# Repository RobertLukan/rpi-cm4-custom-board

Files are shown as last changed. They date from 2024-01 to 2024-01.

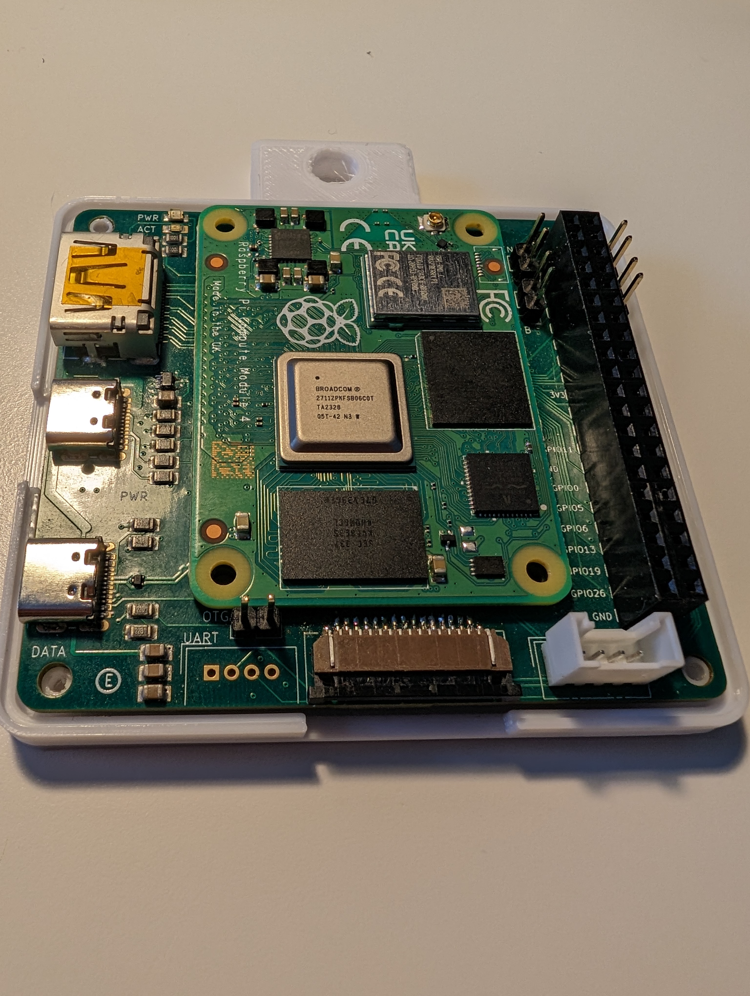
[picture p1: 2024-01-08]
pictures/PXL_20240108_122943070.jpg

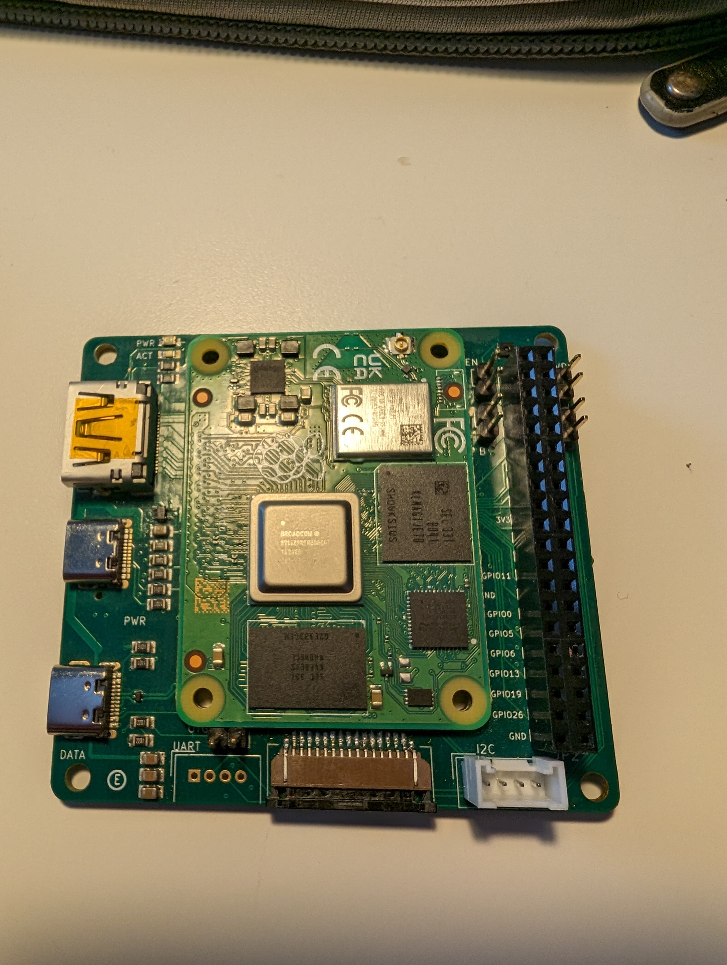
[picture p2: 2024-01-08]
pictures/PXL_20240108_123018562.jpg

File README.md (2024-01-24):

Based on my previous projects I needed a customized RPI4 carrier board with 2 cameras input. The initial idea was taken from this project: https://www.tindie.com/products/dronecz/minimal-carrier-board-for-compute-module-4/.

I made several changes such as 4-layer PCB, added second camera lanes, differential routing for both cameras and HDMI, added temperature sensor, and added I2C and UART connectors.

I have added also two jumpers that allow disabling wireless and Bluetooth. I have tested nearly every connection. SD card connector does not work if you are using RPI4CM with emmc, otherwise, it should(not the fault of this design but the RPI design decision that I was not aware of while making this board)

In general, I am quite happy with the setup. JLCPCB manufactured and assembled most of the parts. However, one board did not have Hirose connectors soldered properly, I have received a coupon. I have not touched the spacing for Hirose connectors, but I found it may be slightly off. It is hard to connect RPI for the first time. But I don't want to modify it as it has been working for several weeks.

USB connector can be used to connect external devices. To flash a CM the dedicated jumper(OTG) needs to be connected . It is just USB2.0 and it is not delivering any power. I have tested powered USB hub/docking station and it is working fine. In this way even Ethernet connection can be used (again being limited to USB2.0)

I also created 3D-printed housing. It is my first 3d design of this type/scale, but it works. It does not have cutouts for HDMI and USB2.0 as I dont need them.

In order to use both cameras, config.txt file has to include both overlays as defined below, for my two cameras:

dtparam=i2c_arm=on

dtoverlay=imx708,cam0

dtoverlay=imx477,cam1

The majority of the connectors were assembled by JLCPCB(without I2C and camera connectors - not available at that time), I have included the production directory where all the details are attached. The positions of parts are not 100% aligned, so make sure if you are asking JLCPCB to assemble parts to align them correctly. It is very important to order the correct camera connector: https://www.digikey.at/en/products/detail/amphenol-cs-fci/SFW15R-1STAE1LF/4270877

I made several design decisions that suited my needs, such as different GPIO header connector, and 4-pin Groove connectors for UART and I2C, so they might not be suitable for your needs.

One important detail, I am powering this board with the Raspberry Pi power supply. Other power supplies with USB C connector might not work as RPI requires quite some power and I would need to implement USB PD.

Update:
I needed power(5V) for an external USB device. I knew that I could connect a powered USB docking station(hub), however, that requires yet another power supply. As I just needed to power the USB microphone, that was an overkill. I looked at my diagram and I noticed that I can take 5V from GPIO and connect one of the pins at the OTG jumper(as shown below). An important detail is that the track is not designed to carry a lot of current, so be reasonable. 



License:
Please feel free to use the design. Released under the following license: 
https://ohwr.org/cern_ohl_p_v2.txt

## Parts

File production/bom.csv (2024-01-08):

Designator | Footprint | Quantity | Value | LCSC Part #
@HOLE0, @HOLE1, @HOLE2, @HOLE3, @HOLE4, @HOLE5, @HOLE6, @HOLE7 |  | 8
ACT0 | CHIPLED_0805_NOOUTLINE | 1 | GREEN
C0, CAMERA0 | SFW15R2STE1LF | 2 | SFW15R-2STE1LF
C1, C2, C3, C4 | C0805 | 4 | 10uF
C5 | C0805 | 1 | 100nF
HDMI0 | HDMI_MOLEX_47151-0001 | 1 | HDMI_MOLEX_47151-0001 | C428484
IC0 | SOT65P210X110-5N | 1 | MC74VHC1G14DFT1G
J1, J2 | DF40C100DS04V51 | 2 | DF40C-100DS-0.4V_51_ | DF40C-100DS-0.4V(51)
JP1, JP3, JP4, JP5, JP6 | PinHeader_1x02_P2.54mm_Vertical | 5 | Jumper_2_Open
JP2 | 2X20 | 1 | PINHD-2X20
PWR0 | CHIPLED_0805_NOOUTLINE | 1 | RED/ORANGE
R1, R2 | R0805 | 2 | 1k
R10, R11 | R0805 | 2 | 2.2k
R3, R4, R5 | R0805 | 3 | 10K
R6, R7, R8, R9 | R0805 | 4 | 5.1k
SD_CARD0 | TFP09-2--12B | 1 | MICRO_SD_CARD_
U1, U2 | NS-Tech_Grove_1x04_P2mm_Vertical | 2 | ~
U3 | Texas_DRT-3 | 1 | TPD2EUSB30A
U4 | Sensirion_DFN-4-1EP_2x2mm_P1mm_EP0.7x1.6mm | 1 | SHTC3
US0, US1 | HRO_31_M_12_USB_C | 2 | HRO_31_M_12_USB_C

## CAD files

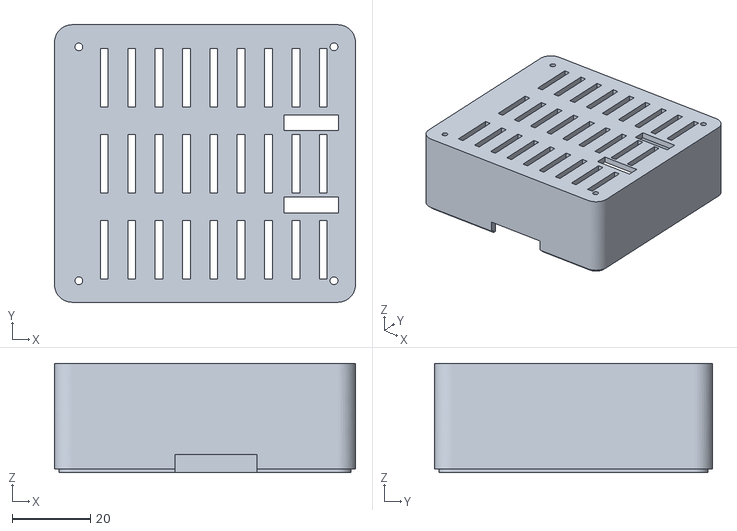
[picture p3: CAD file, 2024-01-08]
Case/RPI Box v1 Top.stl
77.0 x 71.0 x 28.0

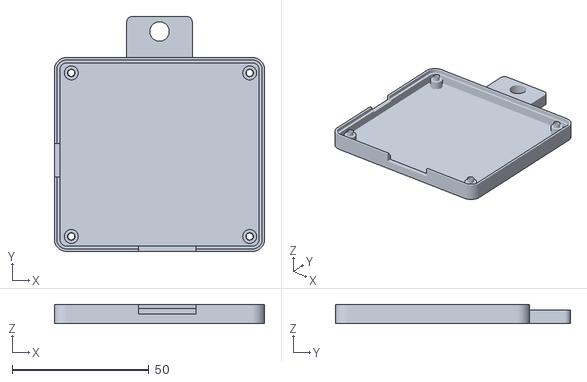
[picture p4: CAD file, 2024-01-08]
Case/RPI Box v1 Bottom.stl
77.0 x 86.0 x 7.00

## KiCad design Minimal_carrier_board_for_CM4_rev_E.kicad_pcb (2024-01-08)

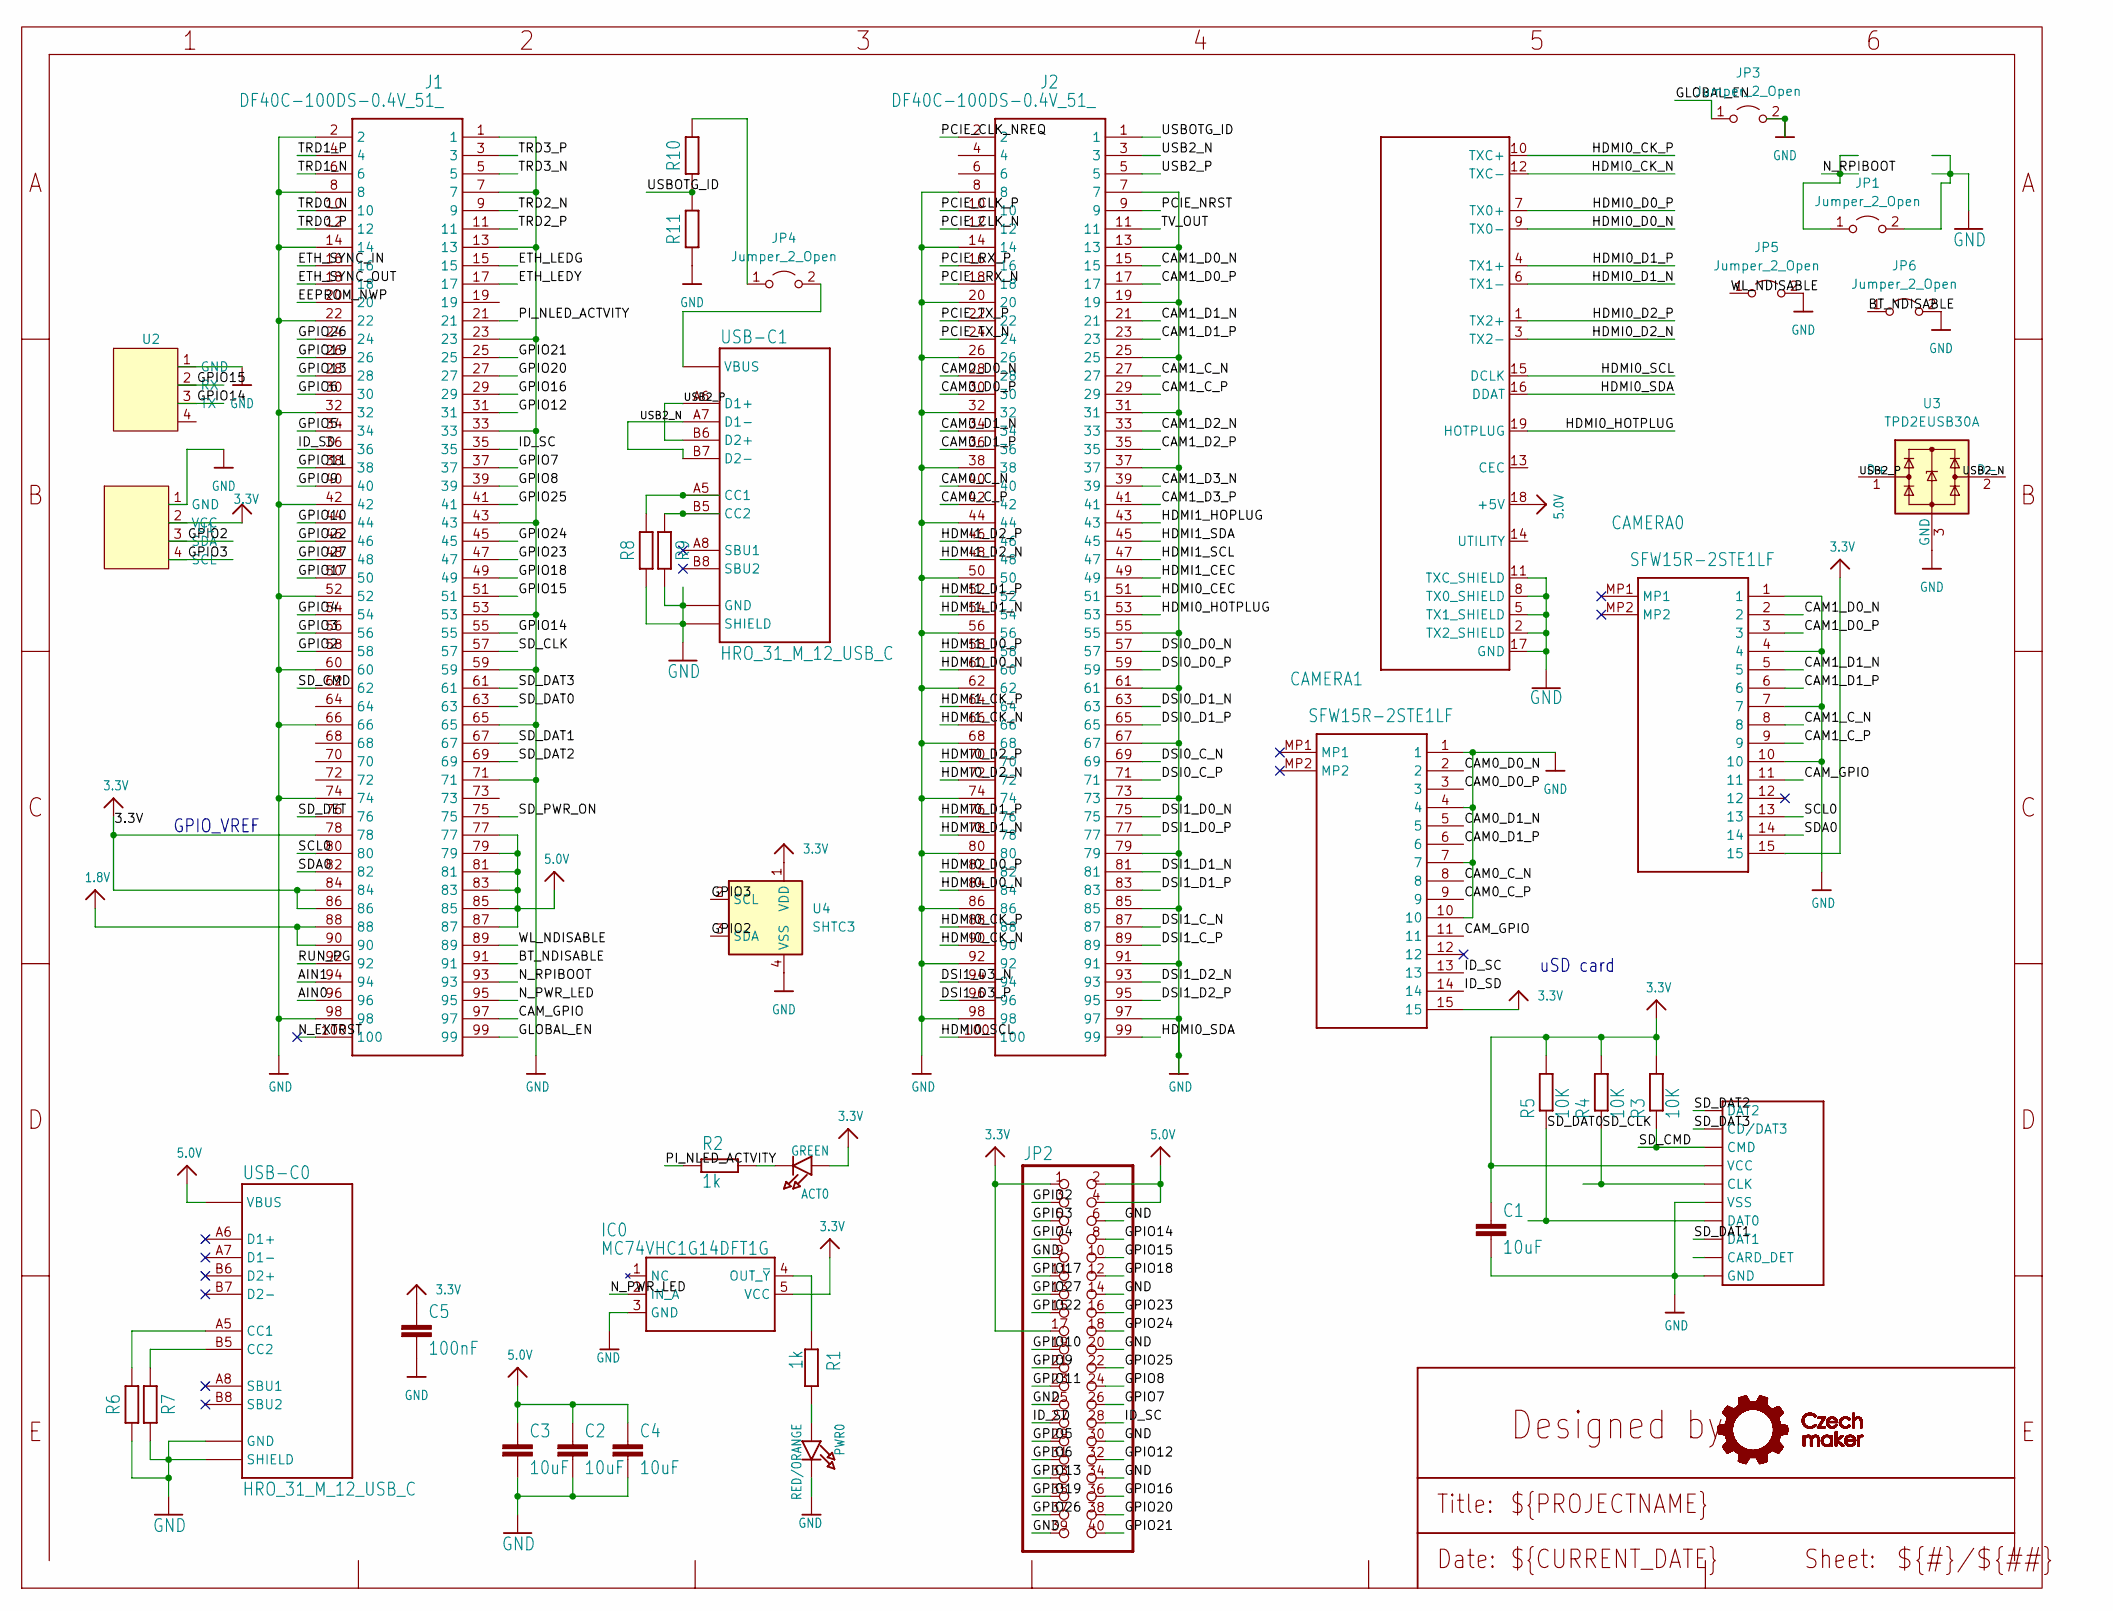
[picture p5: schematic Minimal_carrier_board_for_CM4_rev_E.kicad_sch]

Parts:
ACT0: GREEN; CHIPLED_0805_NOOUTLINE
C1, C2, C3, C4: 10uF; C0805
C5: 100nF; C0805
CAMERA0, CAMERA1: SFW15R-2STE1LF; SFW15R2STE1LF
HDMI0: HDMI_MOLEX_47151-0001; LCSC C428484
IC0: MC74VHC1G14DFT1G; SOT65P210X110-5N
J1: DF40C-100DS-0.4V_51_; DF40C100DS04V51; LCSC DF40C-100DS-0.4V(51)
J2: DF40C-100DS-0.4V_51_; DF40C100DS04V51
JP1, JP3, JP4, JP5, JP6: Jumper_2_Open; PinHeader_1x02_P2.54mm_Vertical
JP2: PINHD-2X20; 2X20
PWR0: RED/ORANGE; CHIPLED_0805_NOOUTLINE
R1, R2: 1k; R0805
R3, R4, R5: 10K; R0805
R6, R7, R8, R9: 5.1k; R0805
R10, R11: 2.2k; R0805
SD_CARD0: MICRO_SD_CARD_; TFP09-2--12B
U1, U2: NS-Tech_Grove_1x04_P2mm_Vertical
U3: TPD2EUSB30A; Texas_DRT-3
U4: SHTC3; Sensirion_DFN-4-1EP_2x2mm_P1mm_EP0.7x1.6mm
USB-C0, USB-C1: HRO_31_M_12_USB_C

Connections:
1.8V: J1.88, J1.90
3.3V: ACT0.A, C1.1, C5.1, CAMERA0.15, CAMERA1.15, IC0.5 (VCC), J1.78, J1.84, J1.86, JP2.1, JP2.17, R3.2, R4.2, R5.2, SD_CARD0.VCC, U1.2 (VCC), U4.1 (VDD); also elsewhere on the board
5.0V: C2.1, C3.1, C4.1, HDMI0.18 (+5V), J1.77, J1.79, J1.81, J1.83, J1.85, J1.87, JP2.2, JP2.4, USB-C0.A4 (VBUS), USB-C0.A9 (VBUS), USB-C0.B4 (VBUS), USB-C0.B9 (VBUS); also elsewhere on the board
/AIN0: J1.96
/AIN1: J1.94
/BT_NDISABLE: J1.91, JP6.1 (A)
/CAM0_C_N: CAMERA1.8, J2.40; also elsewhere on the board
/CAM0_C_P: CAMERA1.9, J2.42; also elsewhere on the board
/CAM0_D0_N: CAMERA1.2, J2.28; also elsewhere on the board
/CAM0_D0_P: CAMERA1.3, J2.30; also elsewhere on the board
/CAM0_D1_N: CAMERA1.5, J2.34; also elsewhere on the board
/CAM0_D1_P: CAMERA1.6, J2.36; also elsewhere on the board
/CAM1_C_N: CAMERA0.8, J2.27
/CAM1_C_P: CAMERA0.9, J2.29
/CAM1_D0_N: CAMERA0.2, J2.15
/CAM1_D0_P: CAMERA0.3, J2.17
/CAM1_D1_N: CAMERA0.5, J2.21
/CAM1_D1_P: CAMERA0.6, J2.23
/CAM1_D2_N: J2.33
/CAM1_D2_P: J2.35
/CAM1_D3_N: J2.39
/CAM1_D3_P: J2.41
/CAM_GPIO: CAMERA0.11, CAMERA1.11, J1.97; also elsewhere on the board
/DSI0_C_N: J2.69
/DSI0_C_P: J2.71
/DSI0_D0_N: J2.57
/DSI0_D0_P: J2.59
/DSI0_D1_N: J2.63
/DSI0_D1_P: J2.65
/DSI1_C_N: J2.87
/DSI1_C_P: J2.89
/DSI1_D0_N: J2.75
/DSI1_D0_P: J2.77
/DSI1_D1_N: J2.81
/DSI1_D1_P: J2.83
/DSI1_D2_N: J2.93
/DSI1_D2_P: J2.95
/DSI1_D3_N: J2.94
/DSI1_D3_P: J2.96
/EEPROM_NWP: J1.20
/ETH_LEDG: J1.15
/ETH_LEDY: J1.17
/ETH_SYNC_IN: J1.16
/ETH_SYNC_OUT: J1.18
/GLOBAL_EN: J1.99, JP3.1 (A)
/GPIO2: J1.58, JP2.3, U1.3 (SDA), U4.3 (SDA)
/GPIO3: J1.56, JP2.5, U1.4 (SCL), U4.2 (SCL)
/GPIO4: J1.54, JP2.7
/GPIO5: J1.34, JP2.29
/GPIO6: J1.30, JP2.31
/GPIO7: J1.37, JP2.26
/GPIO8: J1.39, JP2.24
/GPIO9: J1.40, JP2.21
/GPIO10: J1.44, JP2.19
/GPIO11: J1.38, JP2.23
/GPIO12: J1.31, JP2.32
/GPIO13: J1.28, JP2.33
/GPIO14: J1.55, JP2.8, U2.3 (TX)
/GPIO15: J1.51, JP2.10, U2.2 (RX)
/GPIO16: J1.29, JP2.36
/GPIO17: J1.50, JP2.11
/GPIO18: J1.49, JP2.12
/GPIO19: J1.26, JP2.35
/GPIO20: J1.27, JP2.38
/GPIO21: J1.25, JP2.40
/GPIO22: J1.46, JP2.15
/GPIO23: J1.47, JP2.16
/GPIO24: J1.45, JP2.18
/GPIO25: J1.41, JP2.22
/GPIO26: J1.24, JP2.37
/GPIO27: J1.48, JP2.13
/HDMI0_CEC: J2.51
/HDMI0_CK_N: HDMI0.12 (TXC-), J2.90
/HDMI0_CK_P: HDMI0.10 (TXC+), J2.88
/HDMI0_D0_N: HDMI0.9 (TX0-), J2.84
/HDMI0_D0_P: HDMI0.7 (TX0+), J2.82
/HDMI0_D1_N: HDMI0.6 (TX1-), J2.78
/HDMI0_D1_P: HDMI0.4 (TX1+), J2.76
/HDMI0_D2_N: HDMI0.3 (TX2-), J2.72
/HDMI0_D2_P: HDMI0.1 (TX2+), J2.70
/HDMI0_HOTPLUG: HDMI0.19 (HOTPLUG), J2.53
/HDMI0_SCL: HDMI0.15 (DCLK), J2.100
/HDMI0_SDA: HDMI0.16 (DDAT), J2.99
/HDMI1_CEC: J2.49
/HDMI1_CK_N: J2.66
/HDMI1_CK_P: J2.64
/HDMI1_D0_N: J2.60
/HDMI1_D0_P: J2.58
/HDMI1_D1_N: J2.54
/HDMI1_D1_P: J2.52
/HDMI1_D2_N: J2.48
/HDMI1_D2_P: J2.46
/HDMI1_HOPLUG: J2.43
/HDMI1_SCL: J2.47
/HDMI1_SDA: J2.45
/ID_SC: CAMERA1.13, J1.35, JP2.28; also elsewhere on the board
/ID_SD: CAMERA1.14, J1.36, JP2.27; also elsewhere on the board
/N_EXTRST: J1.100
/N_PWR_LED: IC0.2 (IN_A), J1.95
/N_RPIBOOT: J1.93, JP1.1 (A)
/PCIE_CLK_N: J2.12
/PCIE_CLK_NREQ: J2.2
/PCIE_CLK_P: J2.10
/PCIE_NRST: J2.9
/PCIE_RX_P: J2.16
/PCIE_TX_N: J2.24
/PCIE_TX_P: J2.22
/PCIE__RX_N: J2.18
/PI_NLED_ACTVITY: J1.21, R2.1
/RUN_PG: J1.92
/SCL0: CAMERA0.13, J1.80
/SDA0: CAMERA0.14, J1.82
/SD_CLK: J1.57, R4.1, SD_CARD0.CLK
/SD_CMD: J1.62, R3.1, SD_CARD0.CMD
/SD_DAT0: J1.63, R5.1, SD_CARD0.DAT0
/SD_DAT1: J1.67, SD_CARD0.DAT1
/SD_DAT2: J1.69, SD_CARD0.DAT2
/SD_DAT3: J1.61, SD_CARD0.CD/DAT3
/SD_DET: J1.76
/SD_PWR_ON: J1.75
/TRD0_N: J1.10
/TRD0_P: J1.12
/TRD1_N: J1.6
/TRD1_P: J1.4
/TRD2_N: J1.9
/TRD2_P: J1.11
/TRD3_N: J1.5
/TRD3_P: J1.3
/TV_OUT: J2.11
/USB2_N: J2.3, U3.2 (D-), USB-C1.A7 (D1-), USB-C1.B7 (D2-); also elsewhere on the board
/USB2_P: J2.5, U3.1 (D+), USB-C1.A6 (D1+), USB-C1.B6 (D2+); also elsewhere on the board
/USBOTG_ID: J2.1, R10.1, R11.2
/WL_NDISABLE: J1.89, JP5.1 (A)
GND: C1.2, C2.2, C3.2, C4.2, C5.2, CAMERA0.1, CAMERA0.4, CAMERA0.7, CAMERA0.10, CAMERA1.1, CAMERA1.4, CAMERA1.7, CAMERA1.10, HDMI0.2 (TX2_SHIELD), HDMI0.5 (TX1_SHIELD), HDMI0.8 (TX0_SHIELD), HDMI0.11 (TXC_SHIELD), HDMI0.17 (GND), IC0.3 (GND), J1.1, J1.2, J1.7, J1.8, J1.13, J1.14, J1.22, J1.23, J1.32, J1.33, J1.42, J1.43, J1.52, J1.53, J1.59, J1.60, J1.65, J1.66, J1.71, J1.74, J1.98, J2.7, J2.8, J2.13, J2.14, J2.19, J2.20, J2.25, J2.26, J2.31, J2.32, J2.37, J2.38, J2.44, J2.50, J2.55, J2.56, J2.61, J2.62, J2.67, J2.68, J2.73, J2.74, J2.79, J2.80, J2.85, J2.86, J2.91, J2.92, J2.97, J2.98, JP1.2 (B), JP2.6, JP2.9, JP2.14, JP2.20, JP2.25, JP2.30, JP2.34, JP2.39, JP3.2 (B), JP5.2 (B), JP6.2 (B), PWR0.C, R6.1, R7.2, R8.1, R9.2, R11.1, SD_CARD0.GND, SD_CARD0.GND@1 (GND), SD_CARD0.GND@2 (GND), SD_CARD0.GND@3 (VSS), SD_CARD0.VSS (GND), U1.1 (GND), U2.1 (GND), U3.3 (GND), U4.4 (VSS), USB-C0.A1 (GND), USB-C0.A12 (GND), USB-C0.B1 (GND), USB-C0.B12 (GND), USB-C0.S1 (SHIELD), USB-C0.S2 (SHIELD), USB-C0.S3 (SHIELD), USB-C0.S4 (SHIELD), USB-C1.A1 (GND), USB-C1.A12 (GND), USB-C1.B1 (GND), USB-C1.B12 (GND), USB-C1.S1 (SHIELD), USB-C1.S2 (SHIELD), USB-C1.S3 (SHIELD), USB-C1.S4 (SHIELD); also elsewhere on the board
unnamed: ACT0.C, R2.2
unnamed: IC0.4 (OUT_~Y), R1.1
unnamed: JP4.1 (A), R10.2
unnamed 137: JP4.2 (B), USB-C1.A4 (VBUS), USB-C1.A9 (VBUS), USB-C1.B4 (VBUS), USB-C1.B9 (VBUS); also elsewhere on the board
unnamed: PWR0.A, R1.2
unnamed 139: R6.2, USB-C0.A5 (CC1); also elsewhere on the board
unnamed 140: R7.1, USB-C0.B5 (CC2); also elsewhere on the board
unnamed 141: R8.2, USB-C1.A5 (CC1); also elsewhere on the board
unnamed 142: R9.1, USB-C1.B5 (CC2); also elsewhere on the board

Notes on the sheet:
uSD card
GPIO_VREF

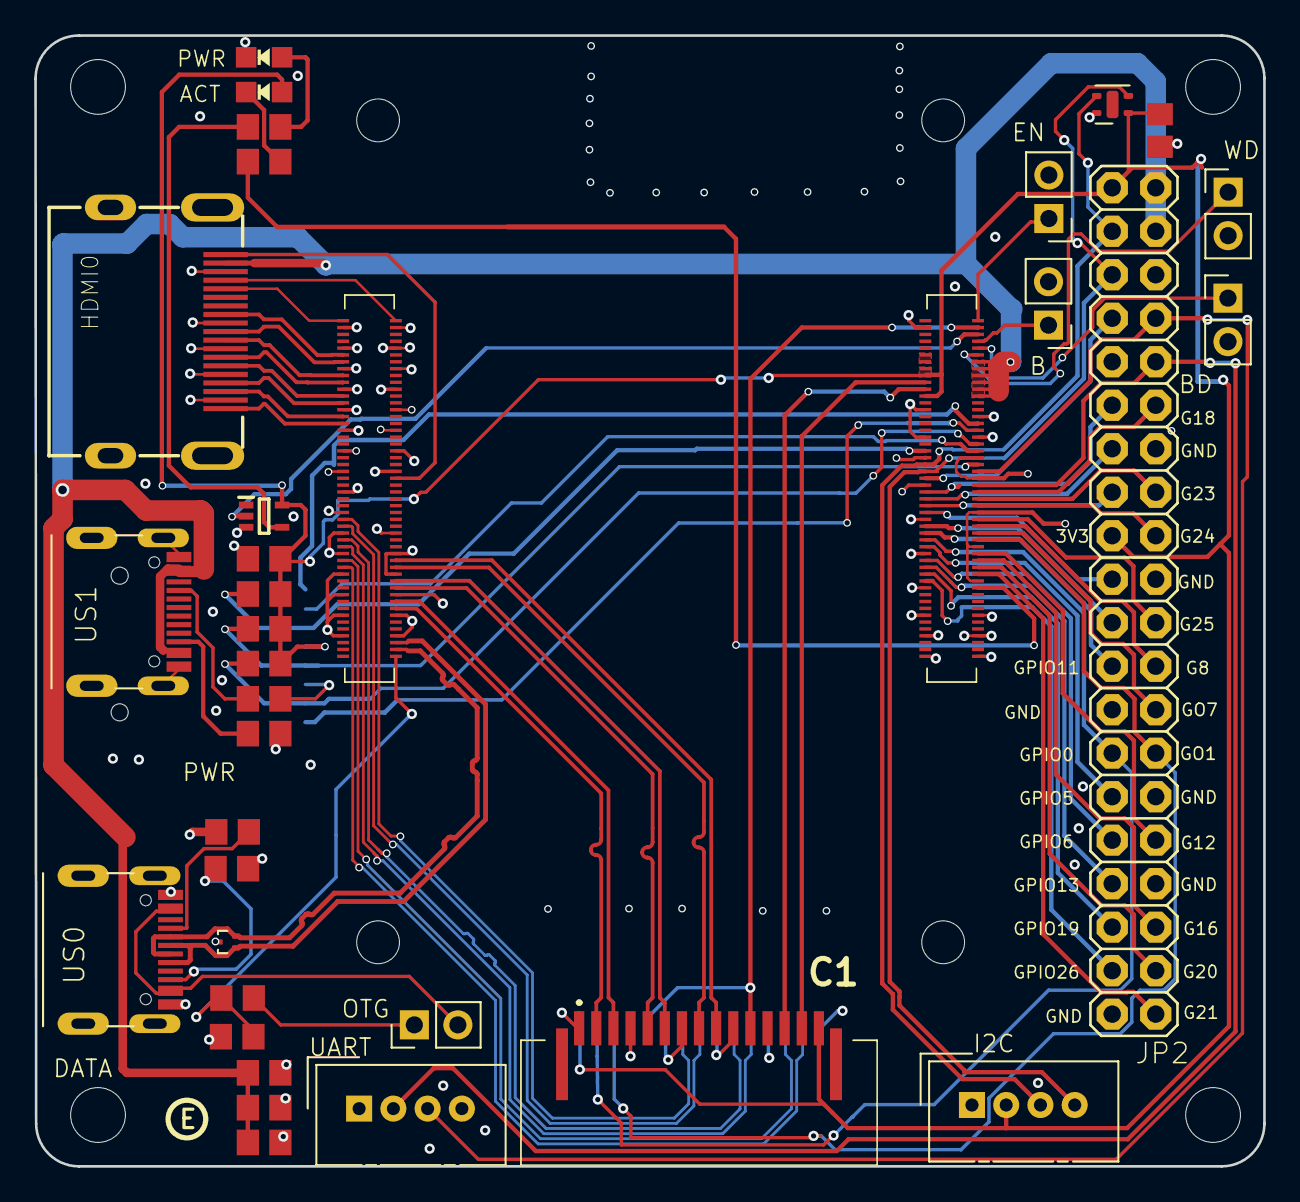
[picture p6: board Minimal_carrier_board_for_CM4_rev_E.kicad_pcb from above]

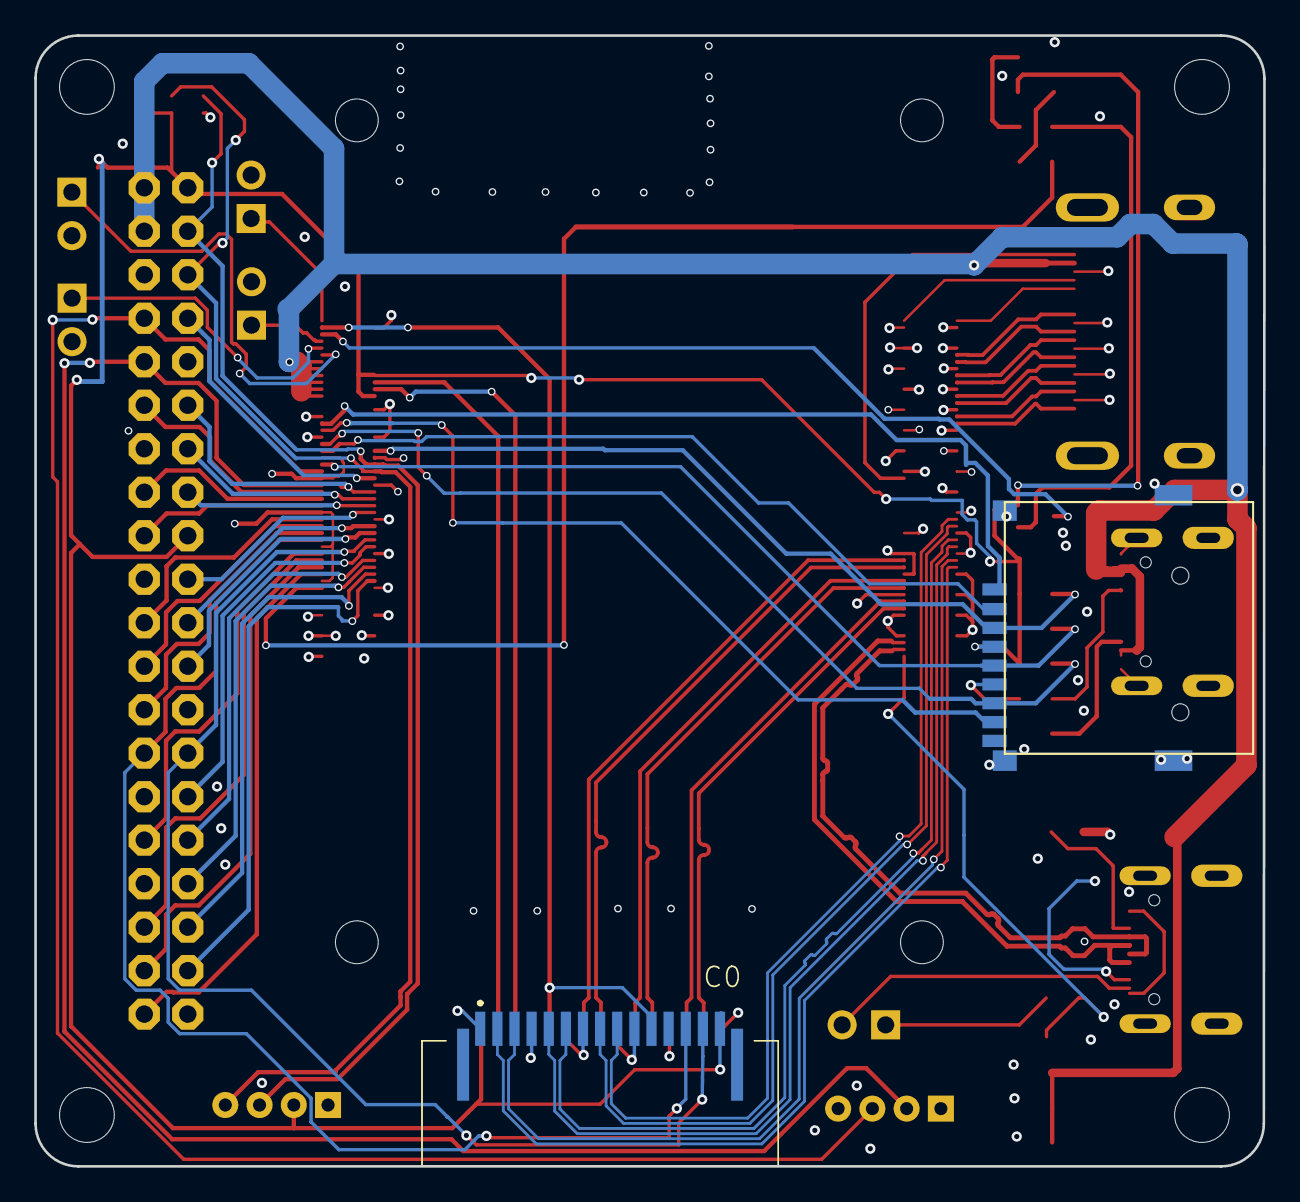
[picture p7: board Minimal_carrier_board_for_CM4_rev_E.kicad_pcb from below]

Board: 4 copper layers, 71.8 x 66.0 mm, 45 parts (2 on the bottom side), 82 nets.

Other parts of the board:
@HOLE0, @HOLE1, @HOLE2, @HOLE3, @HOLE4, @HOLE5, @HOLE6, @HOLE7: (no value)
C0: SFW15R-2STE1LF; SFW15R2STE1LF
US0, US1: HRO_31_M_12_USB_C

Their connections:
3.3V: C0.15; also elsewhere on the board
5.0V: US1.A4 (VBUS), US1.A9 (VBUS), US1.B4 (VBUS), US1.B9 (VBUS); also elsewhere on the board
/CAM0_C_N: C0.8; also elsewhere on the board
/CAM0_C_P: C0.9; also elsewhere on the board
/CAM0_D0_N: C0.2; also elsewhere on the board
/CAM0_D0_P: C0.3; also elsewhere on the board
/CAM0_D1_N: C0.5; also elsewhere on the board
/CAM0_D1_P: C0.6; also elsewhere on the board
/CAM_GPIO: C0.11; also elsewhere on the board
/ID_SC: C0.13; also elsewhere on the board
/ID_SD: C0.14; also elsewhere on the board
/USB2_N: US0.A7 (D1-), US0.B7 (D2-); also elsewhere on the board
/USB2_P: US0.A6 (D1+), US0.B6 (D2+); also elsewhere on the board
GND: C0.1, C0.4, C0.7, C0.10, US0.A1 (GND), US0.A12 (GND), US0.B1 (GND), US0.B12 (GND), US0.S1 (SHIELD), US0.S2 (SHIELD), US0.S3 (SHIELD), US0.S4 (SHIELD), US1.A1 (GND), US1.A12 (GND), US1.B1 (GND), US1.B12 (GND), US1.S1 (SHIELD), US1.S2 (SHIELD), US1.S3 (SHIELD), US1.S4 (SHIELD); also elsewhere on the board
unnamed 137: US0.A4 (VBUS), US0.A9 (VBUS), US0.B4 (VBUS), US0.B9 (VBUS); also elsewhere on the board
unnamed 139: US1.A5 (CC1); also elsewhere on the board
unnamed 140: US1.B5 (CC2); also elsewhere on the board
unnamed 141: US0.A5 (CC1); also elsewhere on the board
unnamed 142: US0.B5 (CC2); also elsewhere on the board

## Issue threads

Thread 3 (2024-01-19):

Plan to support 22-pin CSI connector?

923552514, 2024-01-19:
Hello :-) Thank you for this fantastic project!
Have you considered supporting a 22-pin connector with an additional 2 data lines?
If it is possible to add a 22-pin connector with the implementation of the extra 2 data lines (same pinout as Raspberry Pi Compute Module 4 IO Board), it would enable the use of a 4-lane MIPI-CSI for higher bandwidth.
(In fact, I am currently working on getting Sony IMX183 to work with the cm4. Once completed, I will share the project.)

RobertLukan, 2024-01-19:
I was considering this option. However what I understood from the raspberry forum and RPI4CM data-sheet that RPI4 can only process(encode) one H264 at 1080p. So I wonder is there any benefit bringing additional two lanes to CAM1 ? If there is, one option would be to replace CAM1 connector with 22-pin as CAM0 supports only two lanes anyway.  From the point of view of routing two additional lanes and changing the connector that is not an issue.

923552514, 2024-01-22:
> I was considering this option. However what I understood from the raspberry forum and RPI4CM data-sheet that RPI4 can only process(encode) one H264 at 1080p. So I wonder is there any benefit bringing additional two lanes to CAM1 ? If there is, one option would be to replace CAM1 connector with 22-pin as CAM0 supports only two lanes anyway. From the point of view of routing two additional lanes and changing the connector that is not an issue.

Thank you for your response. The 4-lane CSI interface provides greater bandwidth for data transmission, and the IMX183 with its 20MP sensor requires a larger bandwidth for data transfer.
For example:

 > IMX183, a 20MP camera, recording at 4k resolution, 30fps frame rate, and 10-bit ADC color depth. How many lanes are required at a minimum?
 > MIPI CSI data rate = Resolution Width × Resolution Height × Bit Depth × Frame Rate × (1 + Additional Bandwidth Percentage)
 > (1) According to the Raspberry Pi forum website (https://forums.raspberrypi.com/viewtopic.php?t=311683#p1864026), the maximum MIPI CSI speed is 1Gbps.
 > (2) Rate calculation: 3840 * 2160 * 10 * 30 * (1+20%) = 2985984000bps ≈ 2.98Gbps
 > (3) lane = 2.98 / 1 ≈ 3, so a minimum of 3 lanes is required.

Therefore, for recording 4k resolution videos, a 4-lane CSI interface is needed.
As for why a 22-pin 4-lane interface is still required when the Raspberry Pi only supports H.264, on the one hand, I think it's cool! On the other hand, it's because the bandwidth requirements of most high-resolution CMOS sensors are high (such as the IMX283 lens made by Arducam for DepthAI OAK). With support for a 4-lane CSI interface, I believe the Raspberry Pi will have more possibilities.

RobertLukan, 2024-01-22:
Ok you have convinced me :) I will create another version(dev) with 4-lane CSI connector for CAM1. I have one small improvement to make anyway - adding a jumper or a switch that allows powering USB device on Data port. I will wait a bit more if there are any other suggestions and comments before I make another order with JLCPCB. I will also include a Qwiic connector as suggested.

Do you have any timeframe for your project ?
